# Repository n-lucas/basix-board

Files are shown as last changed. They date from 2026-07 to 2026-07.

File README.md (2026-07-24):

# BASIX Board

Open hardware embedded I/O controller for automation and IoT projects.

## Overview

BASIX is an open hardware embedded controller built primarily with through-hole (THT) components and based on the PIC18F46K20 microcontroller, providing Ethernet, RS485 and other peripherals.

It was designed as an educational platform for learning embedded electronics, prototyping automation systems, and experimenting with industrial communication interfaces and isolated I/O.

The complete hardware design is publicly available, including schematics, PCB layouts, manufacturing files, and documentation.

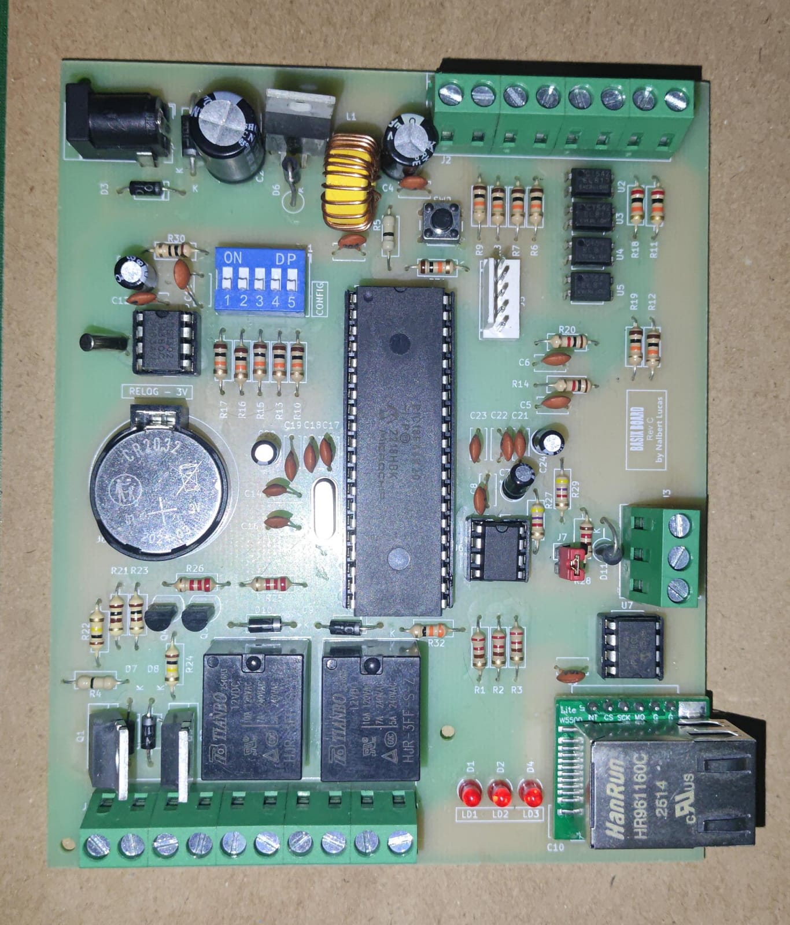
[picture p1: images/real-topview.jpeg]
BASIX Alpha


## Features

- 12VDC power input
- PIC18F46K20 microcontroller (16 MHz)
- Ethernet interface (W5500)
- RS-485 interface
- Real-Time Clock (RTC) with backup battery
- External 128 KB SPI EEPROM
- 4× optically isolated digital inputs
- 2× analog inputs (0–10 V)
- 2× relay outputs
- 2× digital/PWM outputs
- 5-position DIP switch for configuration
- 3x General purpose LEDs (feedback, status, etc)
- ICSP programming header

## Fabrication / Assembly

BASIX was designed with simplicity and accessibility in mind. The board uses mostly through-hole (THT) components, allowing it to be assembled using a standard soldering iron without requiring specialized equipment such as a reflow oven or hot-air station.

The PCB can be manufactured by any standard PCB fabrication service using the Gerber files available in the `hardware/gerbers` directory.

This approach makes the project suitable for hobbyists, students, makers, and anyone interested in learning embedded hardware design or building their own automation controller.

## Repository Structure

| Directory | Description |
|---|---|
| `hardware/kicad/` | Editable KiCad project files, including schematics, PCB layout, symbols, and footprints. |
| `hardware/gerbers/` | Gerber and drill files ready for PCB manufacturing. |
| `hardware/bom/` | Bill of Materials (BOM), including component references, quantities, and part numbers. |
| `docs/` | Technical documentation, hardware architecture, schematics, design notes, and revision history. |
| `images/` | Board photographs, KiCad 3D renders, diagrams, and images used throughout the documentation. |

## Documentation

Additional documentation can be found in the `docs` directory.

Topics include:

- Hardware architecture
- Design decisions
- Revision history

## Expansion Modules

BASIX was designed to be easily expanded through its RS-485 interface.

Developers, students, and makers are encouraged to design and share their own expansion modules, such as:

- Remote digital I/O
- Analog input/output modules
- Relay expansion boards
- Environmental sensors
- Energy monitoring
- LCD/HMI interfaces
- Motor controllers
- Industrial protocol gateways

The goal is to build an open ecosystem of interoperable modules that can communicate with BASIX using a simple RS-485 network.

If you develop an expansion board, feel free to share your project with the community by opening a Pull Request or creating your own repository referencing BASIX.

## Project Status

**Current release**

- Hardware Revision C
- Prototype validated

**Planned**

- Open-source firmware
- Desktop application (Lazarus) for monitoring and controlling I/O

## License

This project is licensed under the CERN Open Hardware Licence Version 2 - Weakly Reciprocal (CERN-OHL-W v2).

See the `LICENSE` file for details.

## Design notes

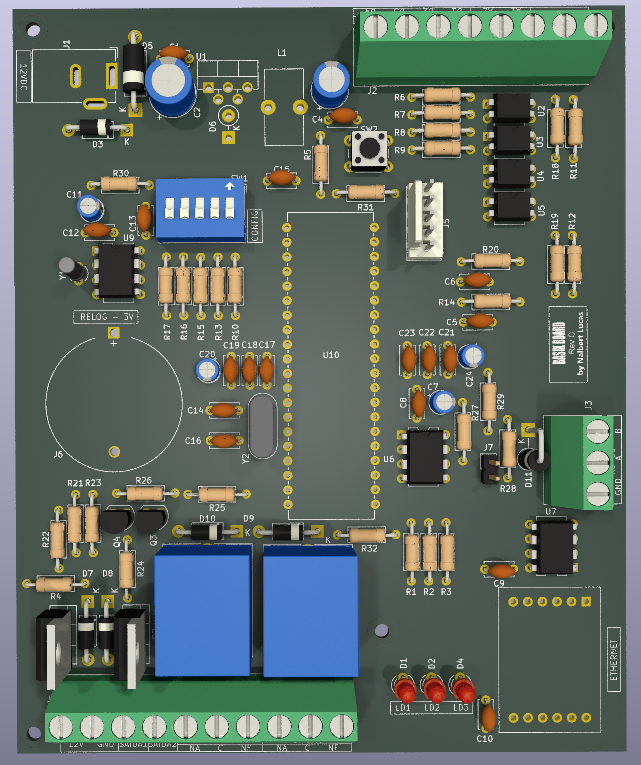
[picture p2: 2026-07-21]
images/virtual-topview.png

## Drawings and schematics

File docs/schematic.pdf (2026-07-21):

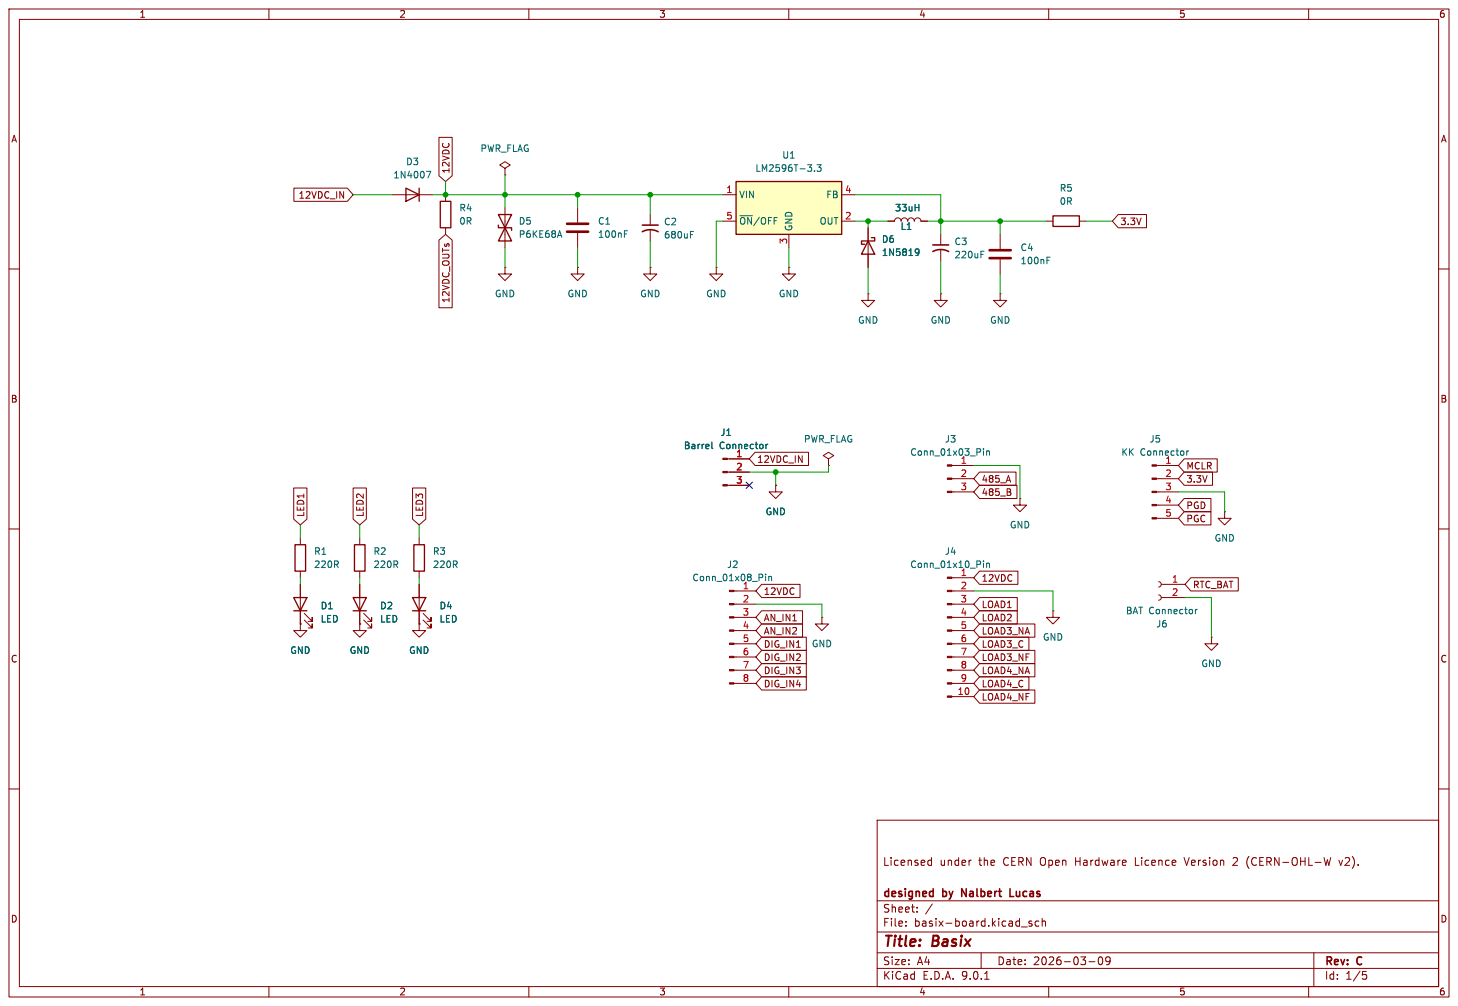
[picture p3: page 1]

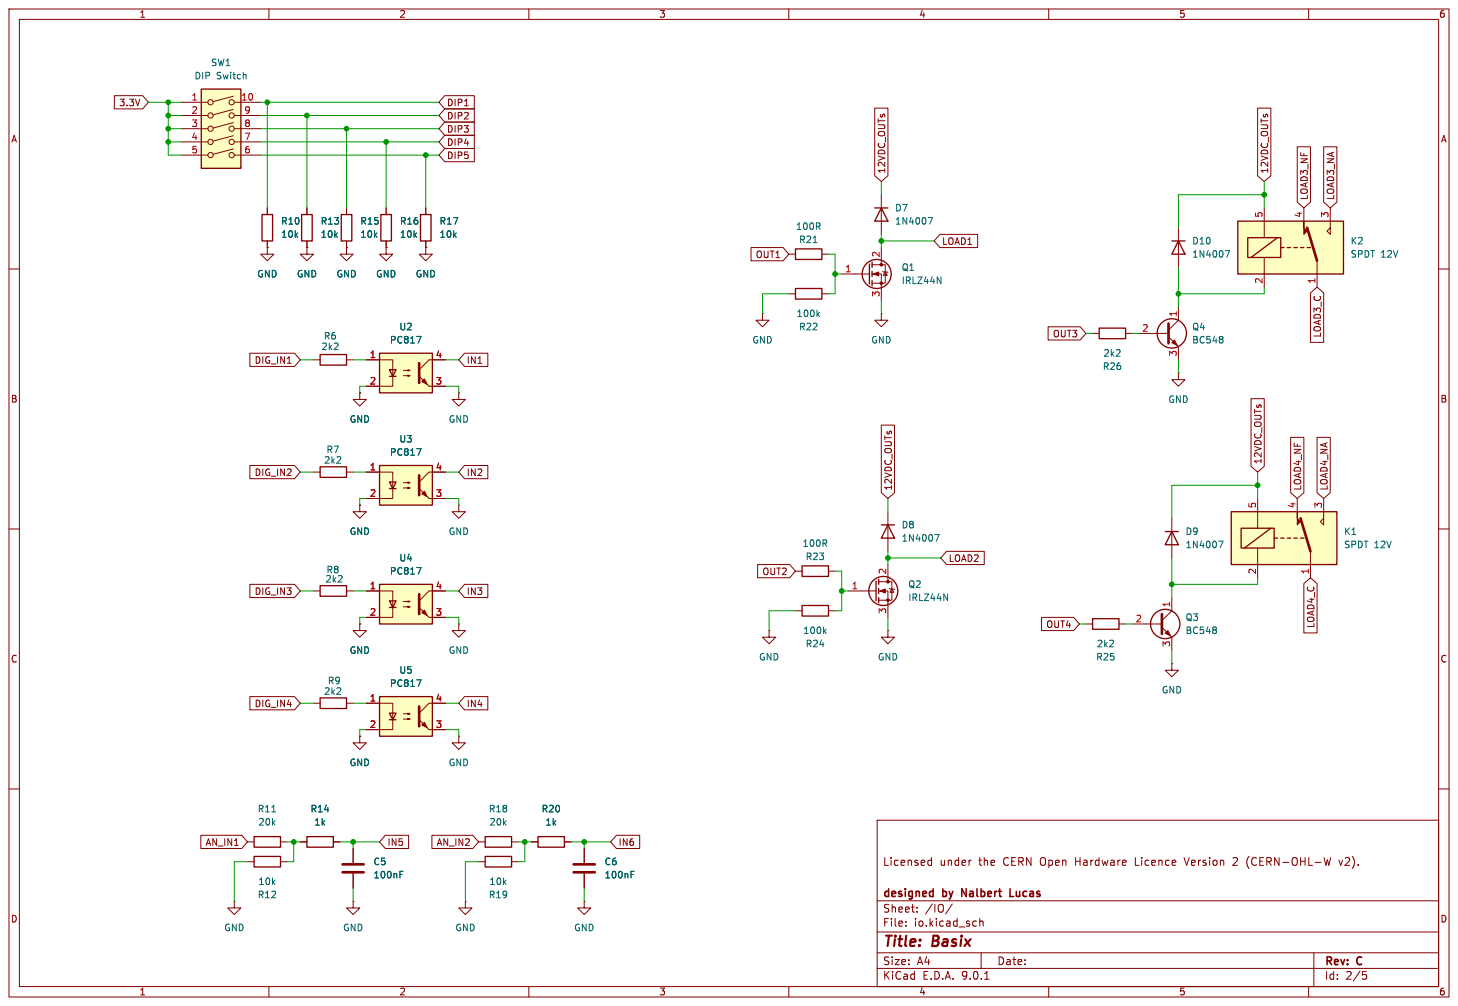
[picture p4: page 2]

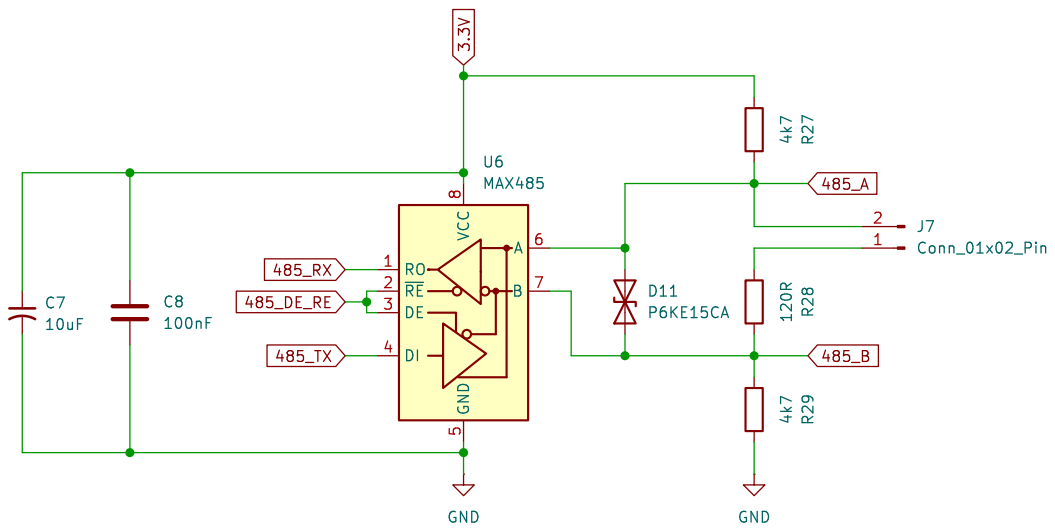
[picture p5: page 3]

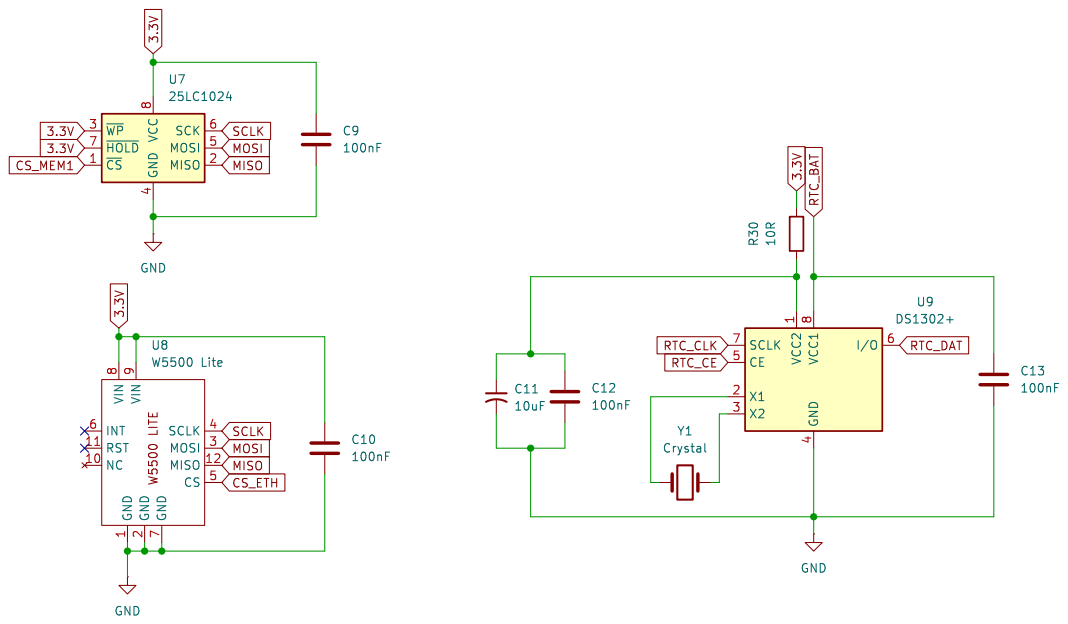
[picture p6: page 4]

7 SCLK 4 MOSI 3 MISO 12 CS 5 U8 W5500 Lite C13

File: peripheral.kicad_sch Sheet: /Peripheral/
Id: 4/5 Title: Basix

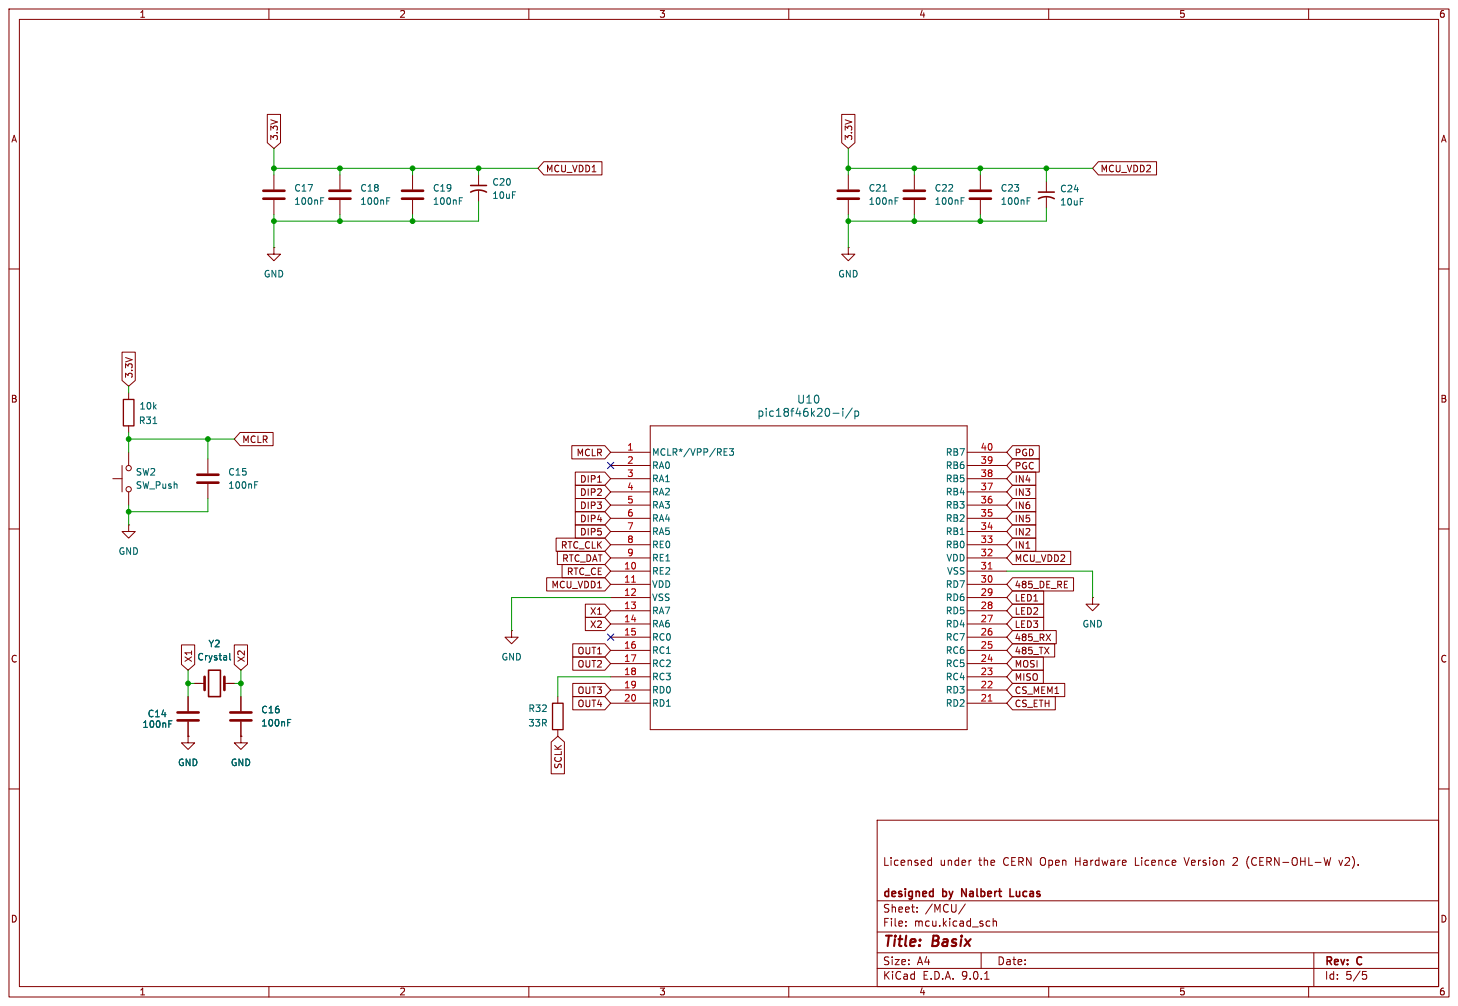
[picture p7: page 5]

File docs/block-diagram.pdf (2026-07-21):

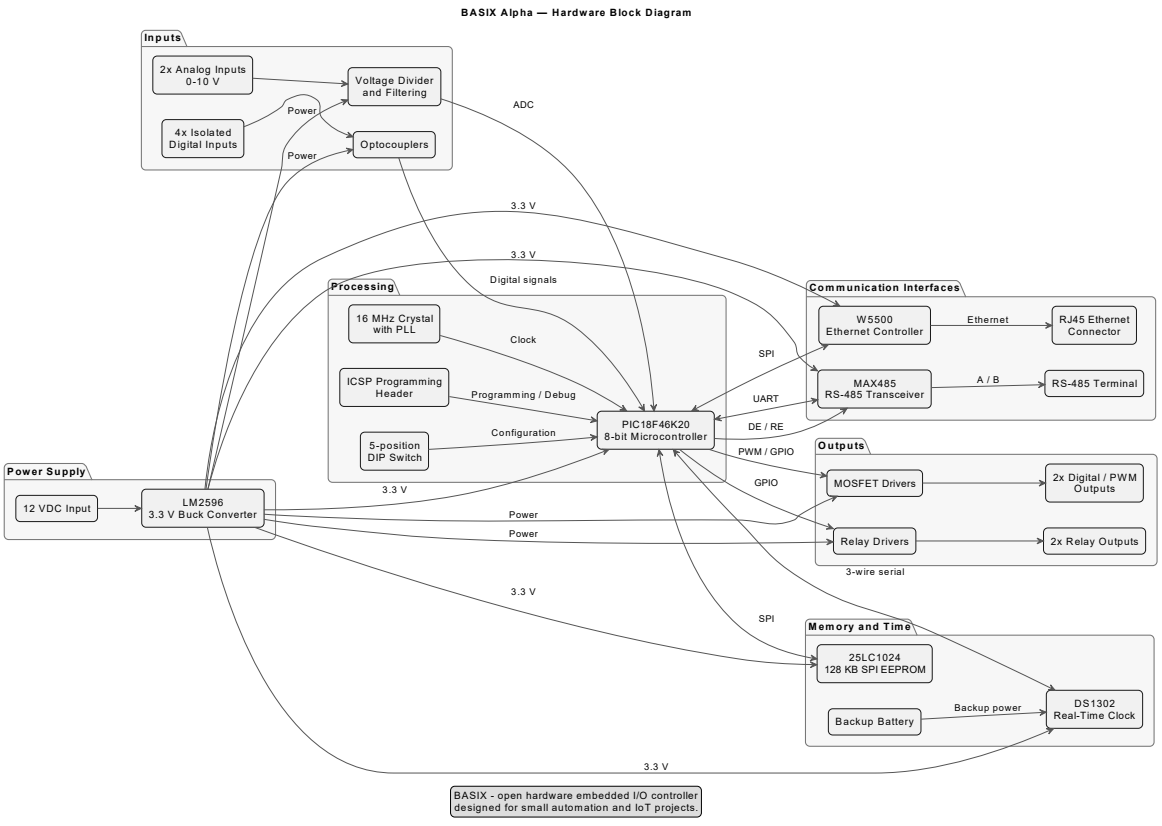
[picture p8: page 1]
P ow e r S u pply; P ro ces sing; C om m unic a tion In te r fa ce s; 12 VDC Input; 3.3 V B uck Converter; PIC18F46K20 8 -bit M icrocontrolle r; 16 MHz C rystal with PLL; ICSP Programming Header; 5 -p osition DIP Switch; RJ45 Ethernet Connector; MAX485 RS-485 Transceive r; RS -485 Terminal; 4x Isolated; D ig ital Inp uts; O ptocouplers; 2x A nalog Inputs; Voltage D ivide r; Relay D rive rs; 2x R elay O utputs; 2x Digital / PW M; Clock; C onfigu ration; Ethe rnet; Backup powe r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

B ASIX Alp ha — H a rdw are Bloc k Diag ram

a nd Filte ring

Ethe rnet C ontrolle r

P rog ramm ing / Debug

O utp uts MOSFET Drivers

3 -w ire se rial

128 KB SPI EEPROM

Real-Time Clock B ackup Batte ry

BASIX - open hardwa re embedded I/O controlle r
designed for sm all autom ation and IoT p rojects.

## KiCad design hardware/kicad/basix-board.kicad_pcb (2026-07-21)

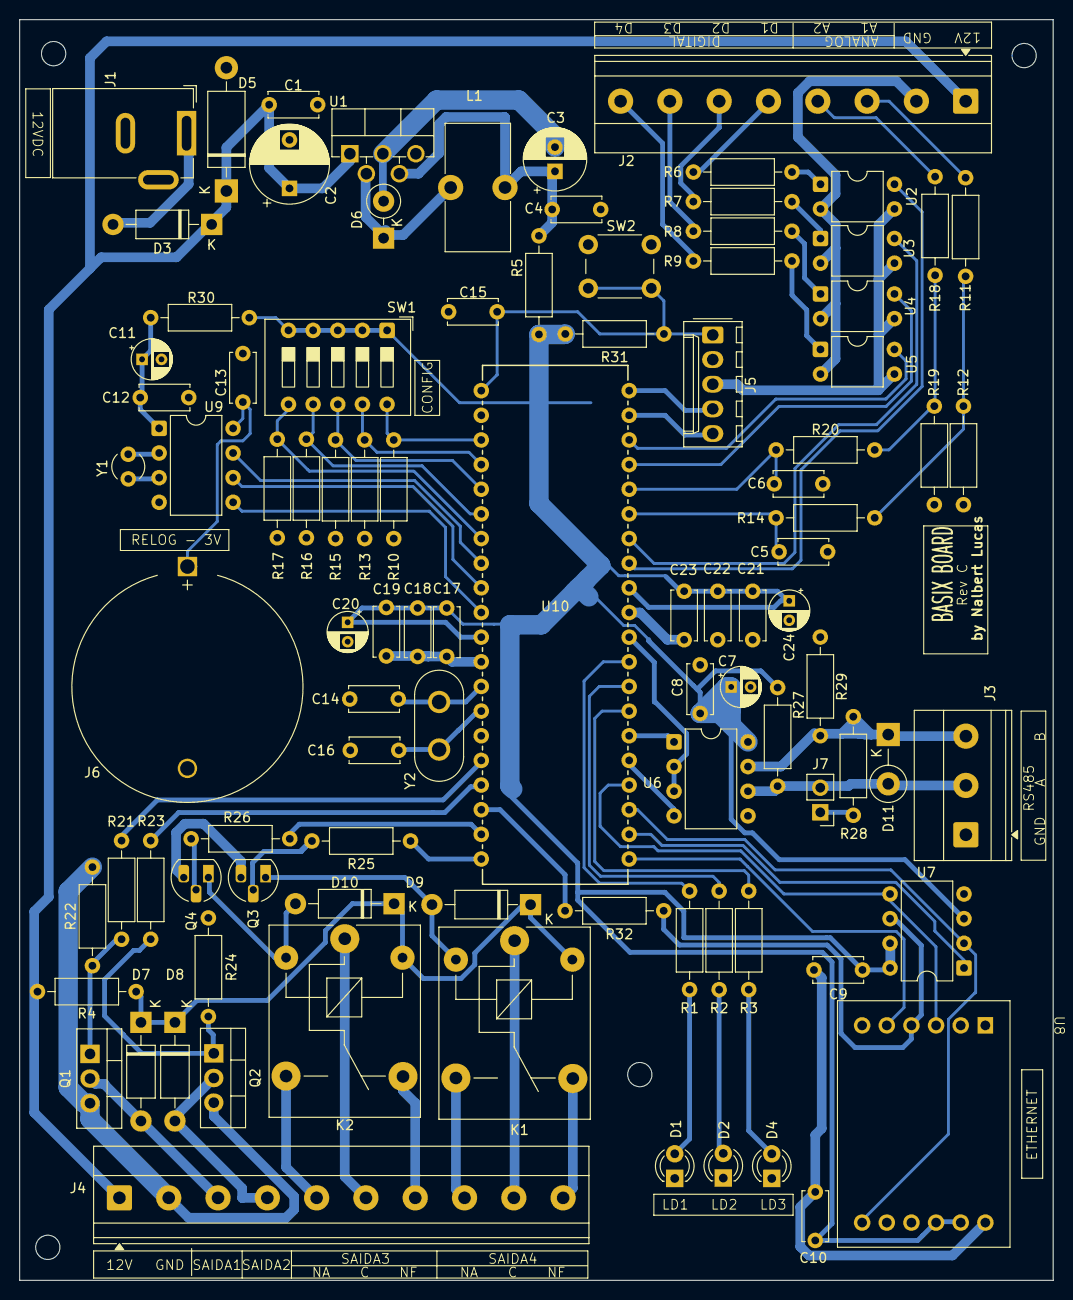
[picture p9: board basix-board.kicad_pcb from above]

Board: 2 copper layers, 106.5 x 129.9 mm, 95 parts (0 on the bottom side), 78 nets.

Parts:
C1, C4, C5, C6, C8, C9, C10, C12, C13, C14, C15, C16, C17, C18, C19, C21, C22, C23: 100nF; C_Disc_D5.0mm_W2.5mm_P5.00mm
C2: 680uF; CP_Radial_D8.0mm_P5.00mm
C3: 220uF; CP_Radial_D6.3mm_P2.50mm
C7, C11, C20, C24: 10uF; CP_Radial_D4.0mm_P2.00mm
D1, D2, D4: LED; LED_D3.0mm
D3, D7, D8, D9, D10: 1N4007; D_DO-41_SOD81_P10.16mm_Horizontal
D5: P6KE68A; D_DO-15_P12.70mm_Horizontal
D6: 1N5819; D_DO-41_SOD81_P3.81mm_Vertical_KathodeUp
D11: P6KE15CA; D_DO-15_P5.08mm_Vertical_KathodeUp
J1: Barrel Connector; BarrelJack_GCT_DCJ200-10-A_Horizontal
J2: Conn_01x08_Pin; TerminalBlock_Phoenix_MKDS-1,5-8-5.08_1x08_P5.08mm_Horizont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
J3: Conn_01x03_Pin; TerminalBlock_Phoenix_MKDS-1,5-3-5.08_1x03_P5.08mm_Horizont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
J4: Conn_01x10_Pin; TerminalBlock_Phoenix_MKDS-1,5-10-5.08_1x10_P5.08mm_Horizon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
J5: KK Connector; Molex_KK-254_AE-6410-05A_1x05_P2.54mm_Vertical
J6: BAT Connector; BatteryHolder_MYOUNG_BS-07-A1BJ001_CR2032
J7: Conn_01x02_Pin; PinHeader_1x02_P2.54mm_Vertical
K1, K2: SPDT 12V; Relay_SPDT_SANYOU_SRD_Series_Form_C
L1: 33uH; L_Toroid_Vertical_L13.0mm_W6.5mm_P5.60mm
Q1, Q2: IRLZ44N; TO-220-3_Vertical
Q3, Q4: BC548; TO-92_HandSolder
R1, R2, R3: 220R; R_Axial_DIN0207_L6.3mm_D2.5mm_P10.16mm_Horizontal
R4, R5: 0R; R_Axial_DIN0207_L6.3mm_D2.5mm_P10.16mm_Horizontal
R6, R7, R8, R9, R25, R26: 2k2; R_Axial_DIN0207_L6.3mm_D2.5mm_P10.16mm_Horizontal
R10, R12, R13, R15, R16, R17, R19, R31: 10k; R_Axial_DIN0207_L6.3mm_D2.5mm_P10.16mm_Horizontal
R11, R18: 20k; R_Axial_DIN0207_L6.3mm_D2.5mm_P10.16mm_Horizontal
R14, R20: 1k; R_Axial_DIN0207_L6.3mm_D2.5mm_P10.16mm_Horizontal
R21, R23: 100R; R_Axial_DIN0207_L6.3mm_D2.5mm_P10.16mm_Horizontal
R22, R24: 100k; R_Axial_DIN0207_L6.3mm_D2.5mm_P10.16mm_Horizontal
R27, R29: 4k7; R_Axial_DIN0207_L6.3mm_D2.5mm_P10.16mm_Horizontal
R28: 120R; R_Axial_DIN0207_L6.3mm_D2.5mm_P10.16mm_Horizontal
R30: 10R; R_Axial_DIN0207_L6.3mm_D2.5mm_P10.16mm_Horizontal
R32: 33R; R_Axial_DIN0207_L6.3mm_D2.5mm_P10.16mm_Horizontal
SW1: DIP Switch; SW_DIP_SPSTx05_Slide_9.78x14.88mm_W7.62mm_P2.54mm
SW2: SW_Push; SW_PUSH_6mm
U1: LM2596T-3.3; TO-220F-5_P3.4x2.06mm_StaggerEven_Lead1.86mm_Vertical
U2, U3, U4, U5: PC817; DIP-4_W7.62mm
U6: MAX485; DIP-8_W7.62mm
U7: 25LC1024; DIP-8_W7.62mm
U8: W5500 Lite; W5500_Lite_2x6_2.54mm_20.32mm
U9: DS1302+; DIP-8_W7.62mm
U10: pic18f46k20-i/p; PDIP40_600MC_MCH
Y1: Crystal; Crystal_AT310_D3.0mm_L10.0mm_Vertical
Y2: Crystal; Crystal_HC50_Vertical

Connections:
3.3V: C7.1, C8.1, C9.1, C10.1, C17.1, C18.1, C19.1, C20.1, C21.1, C22.1, C23.1, C24.1, J5.2, R5.1, R27.2, R30.1, R31.2, SW1.1, SW1.2, SW1.3, SW1.4, SW1.5, U6.8 (VCC), U7.3 (~WP), U7.7 (~HOLD), U7.8 (VCC), U8.8 (VIN), U8.9 (VIN), U10.11 (VDD), U10.32 (VDD)
12VDC: C1.1, C2.1, D3.1 (K), D5.1 (A1), J2.1, J4.1, R4.1, U1.1 (VIN)
12VDC_IN: D3.2 (A), J1.1
12VDC_OUTs: D7.1 (K), D8.1 (K), D9.1 (K), D10.1 (K), K1.5, K2.5, R4.2
485_A: D11.2 (A2), J3.2, J7.2, R27.1, U6.6 (A)
485_B: D11.1 (A1), J3.3, R28.1, R29.2, U6.7 (B)
485_DE_RE: U6.2 (~RE), U6.3 (DE), U10.30 (RD7)
485_RX: U6.1 (RO), U10.26 (RC7)
485_TX: U6.4 (DI), U10.25 (RC6)
AN_IN1: J2.3, R11.2
AN_IN2: J2.4, R18.2
CS_ETH: U8.5 (CS), U10.21 (RD2)
CS_MEM1: U7.1 (~CS), U10.22 (RD3)
DIG_IN1: J2.5, R6.1
DIG_IN2: J2.6, R7.1
DIG_IN3: J2.7, R8.1
DIG_IN4: J2.8, R9.1
DIP1: R10.1, SW1.10, U10.3 (RA1)
DIP2: R13.1, SW1.9, U10.4 (RA2)
DIP3: R15.1, SW1.8, U10.5 (RA3)
DIP4: R16.1, SW1.7, U10.6 (RA4)
DIP5: R17.1, SW1.6, U10.7 (RA5)
GND: C1.2, C2.2, C3.2, C4.2, C5.2, C6.2, C7.2, C8.2, C9.2, C10.2, C11.2, C12.2, C13.2, C14.2, C15.2, C16.2, C17.2, C18.2, C19.2, C20.2, C21.2, C22.2, C23.2, C24.2, D1.1 (K), D2.1 (K), D4.1 (K), D5.2 (A2), D6.2 (A), J1.2, J2.2, J3.1, J4.2, J5.3, J6.2, Q1.3 (S), Q2.3 (S), Q3.3 (E), Q4.3 (E), R10.2, R12.1, R13.2, R15.2, R16.2, R17.2, R19.1, R22.1, R24.1, R29.1, SW2.1, U1.3 (GND), U1.5 (~ON/OFF), U2.2, U2.3, U3.2, U3.3, U4.2, U4.3, U5.2, U5.3, U6.5 (GND), U7.4 (GND), U8.1 (GND), U8.2 (GND), U8.7 (GND), U9.4 (GND), U10.12 (VSS), U10.31 (VSS)
IN1: U2.4, U10.33 (RB0)
IN2: U3.4, U10.34 (RB1)
IN3: U4.4, U10.37 (RB4)
IN4: U5.4, U10.38 (RB5)
IN5: C5.1, R14.1, U10.35 (RB2)
IN6: C6.1, R20.1, U10.36 (RB3)
LED1: R1.2, U10.29 (RD6)
LED2: R2.2, U10.28 (RD5)
LED3: R3.2, U10.27 (RD4)
LOAD1: D7.2 (A), J4.3, Q1.2 (D)
LOAD2: D8.2 (A), J4.4, Q2.2 (D)
LOAD3_C: J4.6, K2.1
LOAD3_NA: J4.5, K2.3
LOAD3_NF: J4.7, K2.4
LOAD4_C: J4.9, K1.1
LOAD4_NA: J4.8, K1.3
LOAD4_NF: J4.10, K1.4
MCLR: C15.1, J5.1, R31.1, SW2.2, U10.1 (MCLR*/VPP/RE3)
MISO: U7.2 (MISO), U8.12 (MISO), U10.23 (RC4)
MOSI: U7.5 (MOSI), U8.3 (MOSI), U10.24 (RC5)
unnamed: D1.2 (A), R1.1
unnamed: D2.2 (A), R2.1
unnamed: D4.2 (A), R3.1
unnamed: D6.1 (K), L1.1, U1.2 (OUT)
unnamed: D9.2 (A), K1.2, Q3.1 (C)
unnamed: D10.2 (A), K2.2, Q4.1 (C)
unnamed: J7.1, R28.2
unnamed: Q1.1 (G), R21.2, R22.2
unnamed: Q2.1 (G), R23.2, R24.2
unnamed: Q3.2 (B), R25.2
unnamed: Q4.2 (B), R26.2
unnamed: R6.2, U2.1
unnamed: R7.2, U3.1
unnamed: R8.2, U4.1
unnamed: R9.2, U5.1
unnamed: R11.1, R12.2, R14.2
unnamed: R18.1, R19.2, R20.2
unnamed: C3.1, C4.1, L1.2, R5.2, U1.4 (FB)
unnamed: C11.1, C12.1, R30.2, U9.1 (VCC2)
unnamed: U9.2 (X1), Y1.1
unnamed: U9.3 (X2), Y1.2
unnamed: R32.1, U10.18 (RC3)
OUT1: R21.1, U10.16 (RC1)
OUT2: R23.1, U10.17 (RC2)
OUT3: R26.1, U10.19 (RD0)
OUT4: R25.1, U10.20 (RD1)
PGC: J5.5, U10.39 (RB6)
PGD: J5.4, U10.40 (RB7)
RTC_BAT: C13.1, J6.1, U9.8 (VCC1)
RTC_CE: U9.5 (CE), U10.10 (RE2)
RTC_CLK: U9.7 (SCLK), U10.8 (RE0)
RTC_DAT: U9.6 (I/O), U10.9 (RE1)
SCLK: R32.2, U7.6 (SCK), U8.4 (SCLK)
X1: C14.1, U10.13 (RA7), Y2.1
X2: C16.1, U10.14 (RA6), Y2.2

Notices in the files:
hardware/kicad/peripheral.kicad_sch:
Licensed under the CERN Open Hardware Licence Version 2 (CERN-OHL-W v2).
